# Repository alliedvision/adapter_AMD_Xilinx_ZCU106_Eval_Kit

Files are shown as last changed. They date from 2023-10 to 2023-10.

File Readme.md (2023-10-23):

# Allied Vision Adapter Board CSI-2 for AMD Xilinx ZCU106 Eval Kit

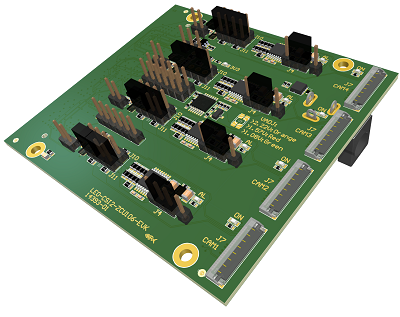
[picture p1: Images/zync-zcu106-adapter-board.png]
zync zcu106 adapter board


This repository contains open hardware design files for an adapter board supporting the Allied Vision Alvium CSI-2 camera pinout to AMD Xilinx ZCU106 Eval Kit. The board allows the user to interface with up to four Alvium MIPI CSI-2 compatible cameras over a Flexible Flat Cable (FFC) connector.

You can also purchase the adapter from [Allied Vision](https://www.alliedvision.com/en/products/accessories/interface-connections/#!?cameraInterfacefilter=10) or from our [distributors](https://www.alliedvision.com/en/avt-locations/avt-distributors/).

## Getting Started

These instructions will get you a copy of the design files to make your own adapter boards for development and testing purposes. 
The board can be produced and assembled using the provided design files. Please take a look at the mechanical layers for more information regarding the PCB stackup recommended for fabrication. 

More information is available on our website:

* [User Guide (PDF)](https://cdn.alliedvision.com/fileadmin/content/documents/products/accessories/embedded/user-guide/Xilinx-ZCU106_Adapter_User-Guide.pdf)
* [Accessories webpage](https://www.alliedvision.com/en/products/accessories/interface-connections/#!?cameraInterfacefilter=10) 
* [Accessories download webpage](https://www.alliedvision.com/en/support/accessory-documentation/)
* [Alvium CSI-2 download webpage](https://www.alliedvision.com/en/support/technical-documentation/alvium-csi-2-documentation/) 

### Prerequisites

* A running installation of Altium.
* A PCB producer & PCBA manufacturer or some soldering skills.
* AMD Xilinx Zynq UltraScale+ MPSoC ZCU106 Evaluation Kit
* Supported MIPI CSI-2 FPC cables, Allied Vision product codes
 18947, 12316, 12317, 12318 
* [Allied Vision Alvium CSI-2 cameras](https://www.alliedvision.com/en/products/embedded-vision-cameras.html)

### Installing

Open the *CSI2-ZCU106-EVK_Rev01.PrjPcb* project file in your Altium environment.

## Built With

[Altium Designer 22](https://www.altium.com/altium-designer/de)
 
## License

This project is licensed under the MIT License - see the [LICENSE](LICENSE) file for details

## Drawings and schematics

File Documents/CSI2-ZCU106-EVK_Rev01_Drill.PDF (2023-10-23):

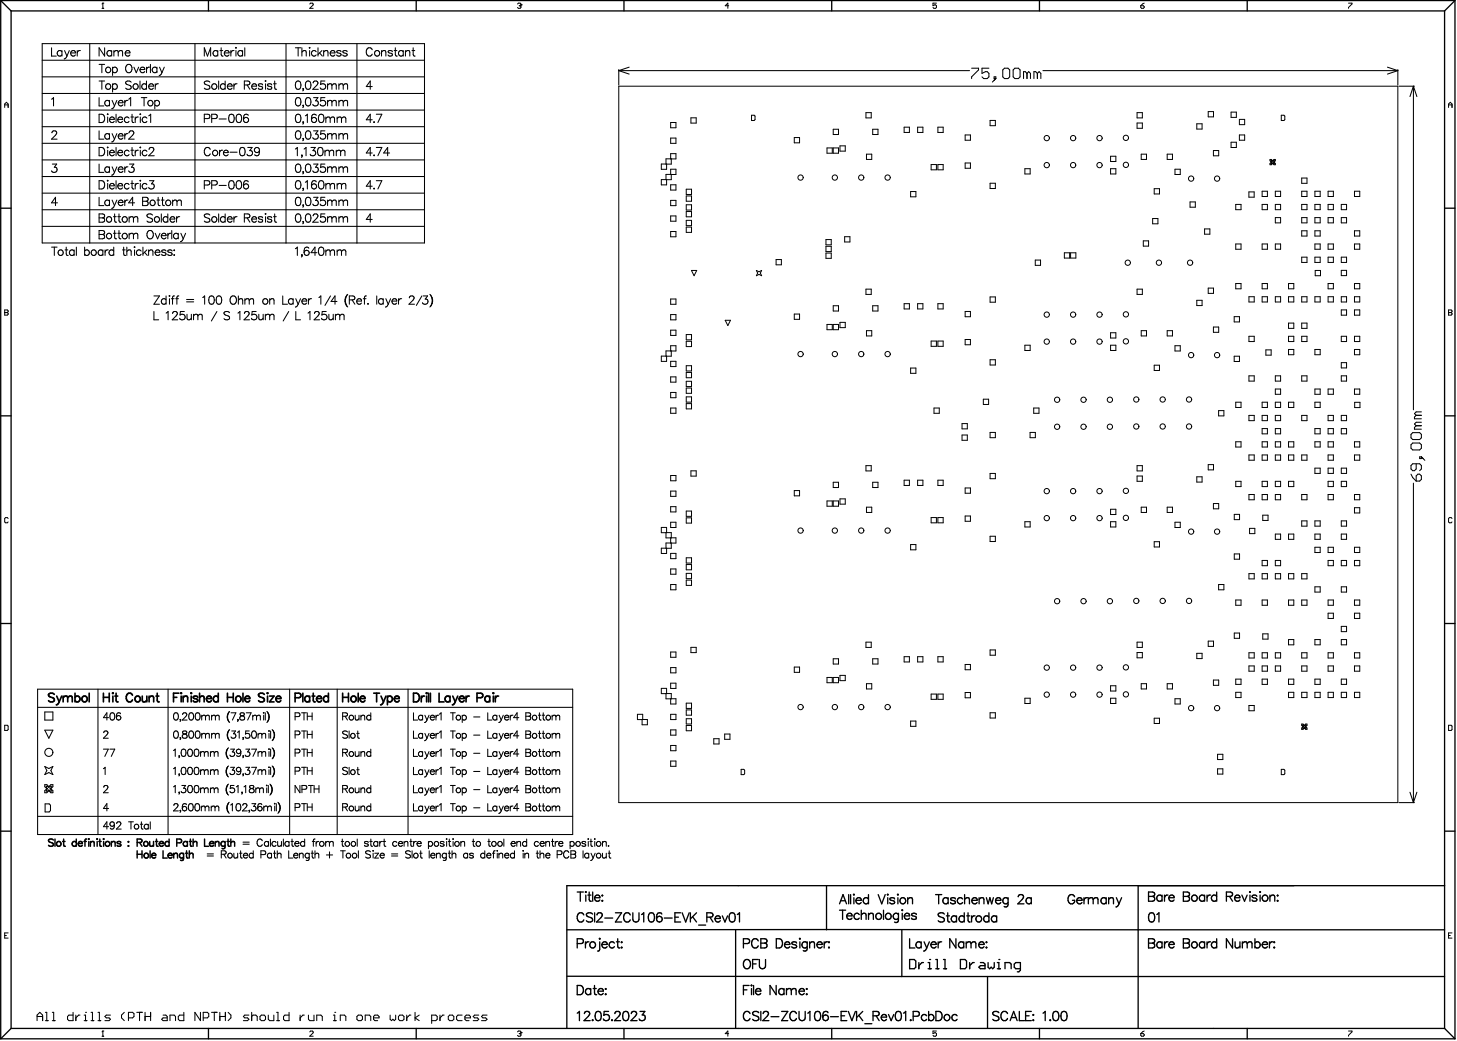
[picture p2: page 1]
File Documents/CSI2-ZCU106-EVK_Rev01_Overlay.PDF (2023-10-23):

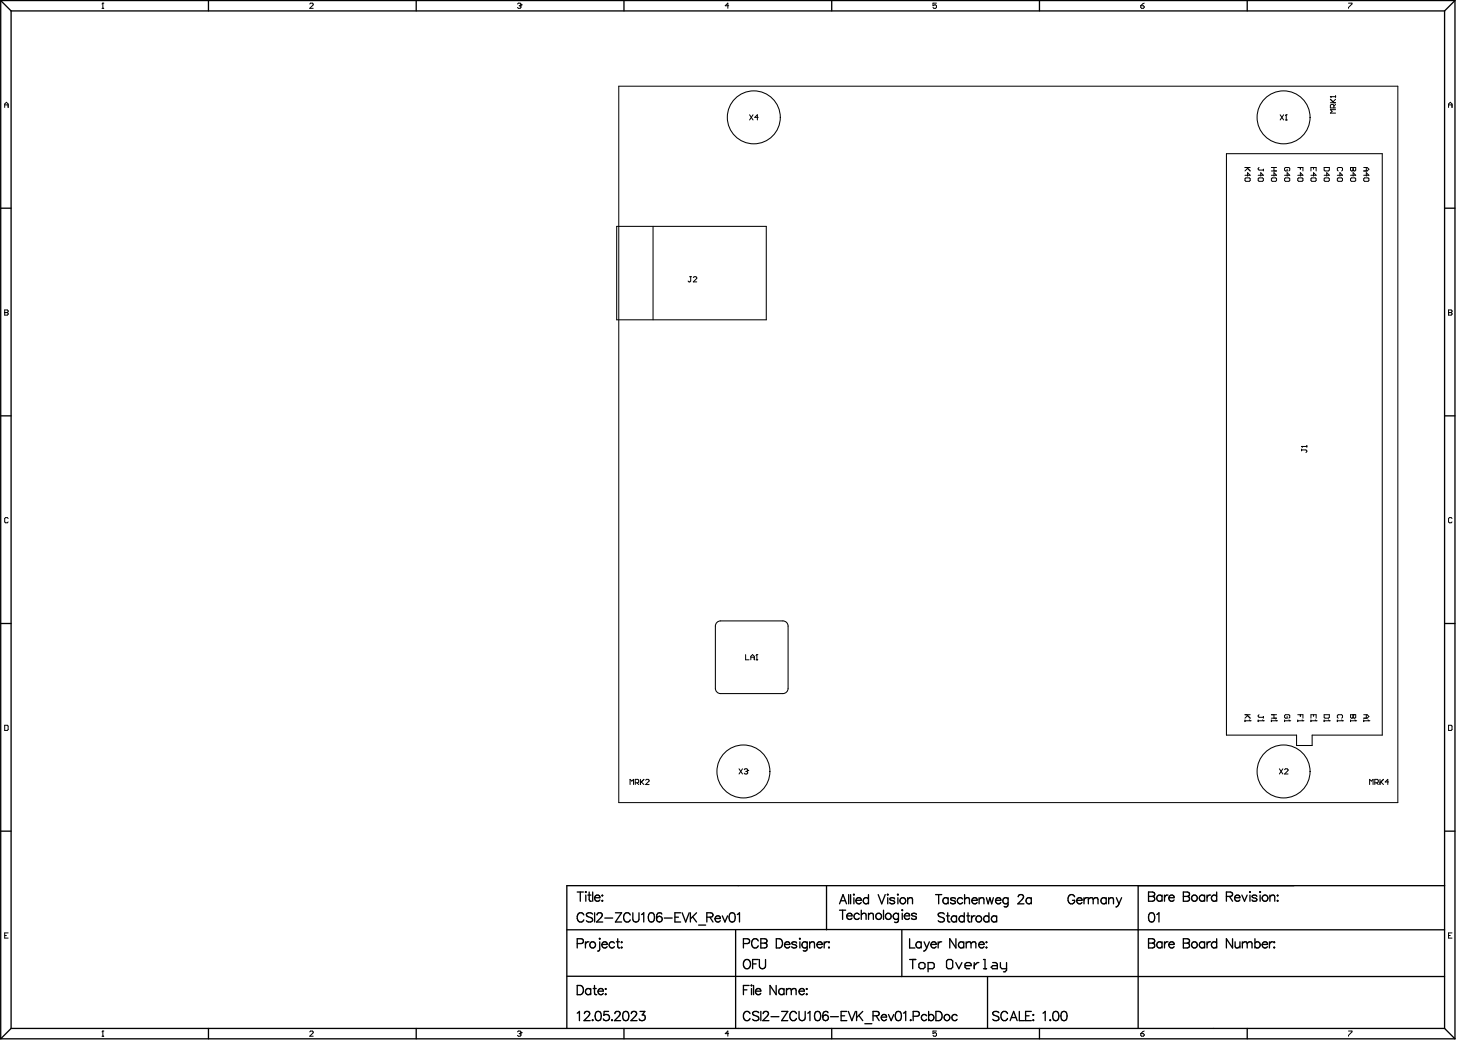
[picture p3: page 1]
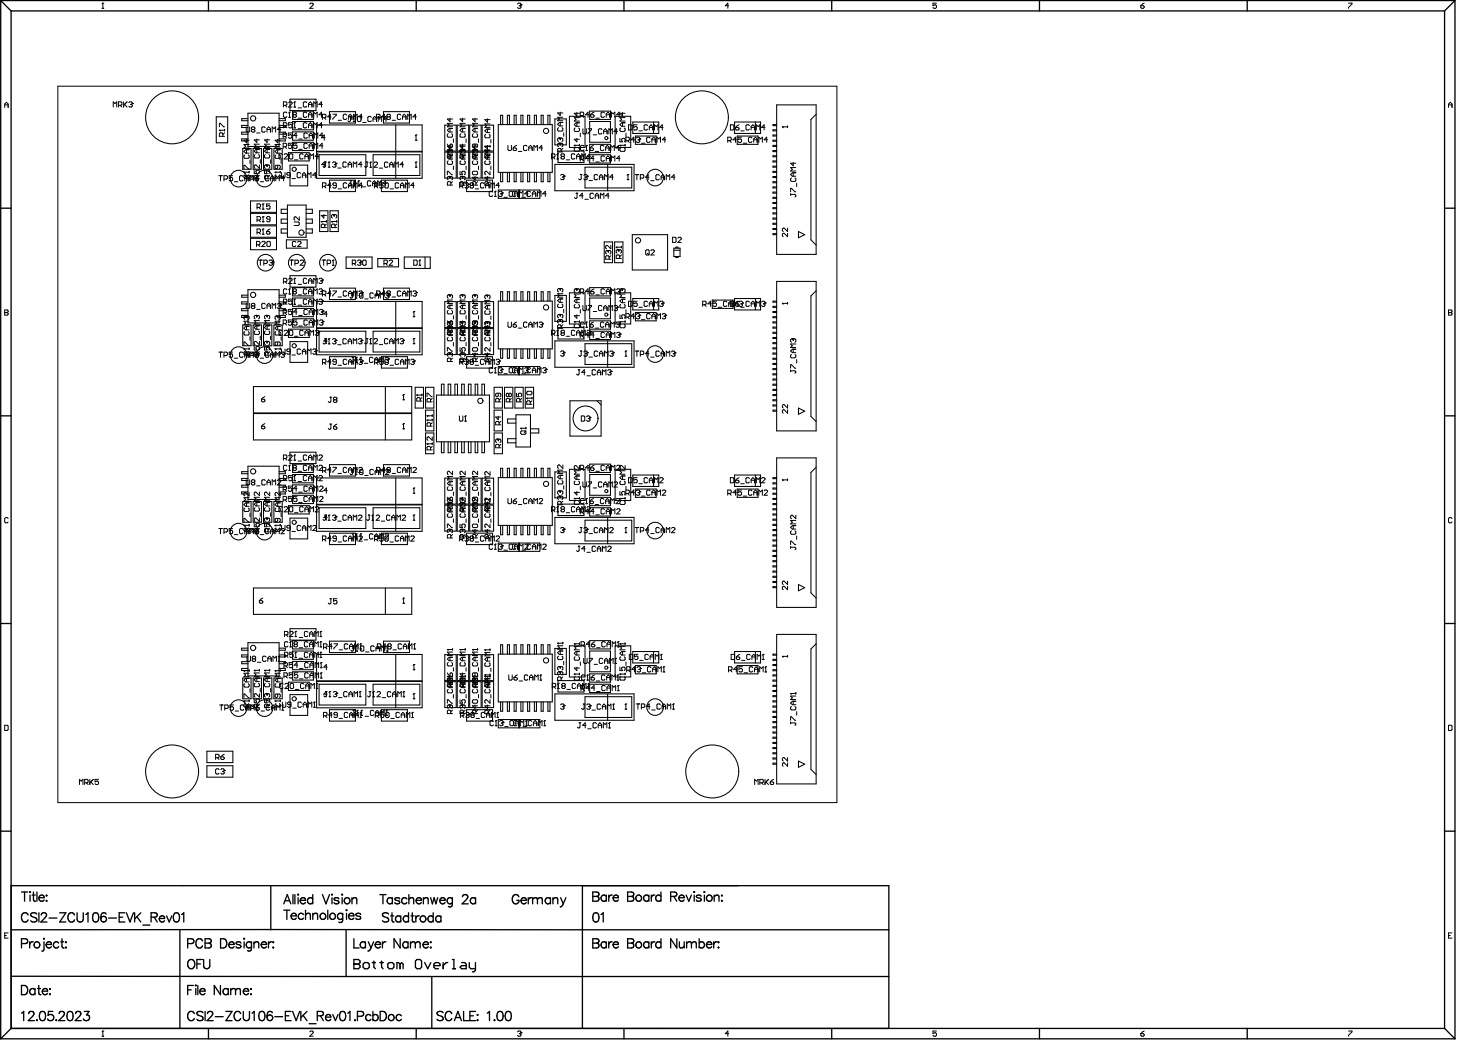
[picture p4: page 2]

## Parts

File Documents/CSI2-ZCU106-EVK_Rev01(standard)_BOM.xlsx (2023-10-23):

 | Bill of Materials | CSI2-ZCU106-EVK_Rev01
 | Project :
 | PCBA : |  | Revision : | 01
 | PCB : |  | Revision : | 01
 | Variant : | standard
 | Schematic : | CSI2-ZCU106-EVK_Rev01 | Schematic.pdf
 | Placement : | CSI2-ZCU106-EVK_Rev01 | Overlay.pdf
 | Report Date : | 12.05.2023 | 14:08
 | Alternative Parts :
Quantity | Designator | Comment | Footprint | Description | Manufacturer | Manufacturer Part Number | KHK Part Number
25 | C1_CAM1, C1_CAM2, C1_CAM3, C1_CAM4, C2, C13_CAM1, C13_CAM2, C13_CAM3, C13_CAM4, C16_CAM1, C16_CAM2, C16_CAM3, C16_CAM4, C17_CAM1, C17_CAM2, C17_CAM3, C17_CAM4, C19_CAM1, C19_CAM2, C19_CAM3, C19_CAM4, C20_CAM1, C20_CAM2, C20_CAM3, C20_CAM4 | 100n | C-0402_0.55 | Capacitor Ceramic SMD/0402/16V/X7R/10% | several | several | K8340114
1 | C3 | NL | C-0603_1.0 | Capacitor Ceramic SMD/0603/50V/X7R/10% | several | several
8 | C14_CAM1, C14_CAM2, C14_CAM3, C14_CAM4, C15_CAM1, C15_CAM2, C15_CAM3, C15_CAM4 | 10u | C-0805_1.4 | Capacitor Ceramic SMD/0805/16V/X5R/10% | several | several | K8340151
4 | C18_CAM1, C18_CAM2, C18_CAM3, C18_CAM4 | 100p | C-0402_0.55 | Capacitor Ceramic SMD/0402/50V/X7R/10% | several | several | K8340145
5 | D1, D6_CAM1, D6_CAM2, D6_CAM3, D6_CAM4 | GREEN | D-0603-LED | Chip LED green 430mcd | Würth | 150060GS75000 | 8172
1 | D2 | ESD9B5.0ST5G | D-SOD923 | DIODE TVS; 400W; 5.8-7.8V; BIDIRECT | ON Semiconductor | ESD9B5.0ST5G | 7250
1 | D3 | RT/GN | LED-PLCC4 | LED red/green | OSRAM | LSG T67K-JL-1+HK-1 | 11105
4 | D5_CAM1, D5_CAM2, D5_CAM3, D5_CAM4 | RED | D-0603-LED | Chip LED red 250mcd | Würth | 150060RS75000 | 8145
1 | J1 | FMC HPC Male | J-ASP-134488-01 | CON FMC HPC MALE 10MM | Samtec | ASP-134488-01 | 9159
1 | J2 | PowerJack | CON_RAPC722 | Switchcraft PowerJack RAPC722 / 2.1mm (Inner) / 6mm (Outer) | Switchcraft | RAPC722X | K7600556
12 | J3_CAM1, J3_CAM2, J3_CAM3, J3_CAM4, J12_CAM1, J12_CAM2, J12_CAM3, J12_CAM4, J13_CAM1, J13_CAM2, J13_CAM3, J13_CAM4 | Jumper | J-JUMPER-2.54 | CON/JUMPER/STC02SYAN; 2-pin; 2.54mm; 3A; FEMALE; VERTICAL; BLACK | several | several | 13444
4 | J4_CAM1, J4_CAM2, J4_CAM3, J4_CAM4 | CON1x3 | CON 1x3 RM2.54 | Header Vertical, 1x3 Pos, Pitch 2.54mm, Contact Length Mating 6.00mm, Contact Length Post 3.00mm, Insulation Height 2.54mm, Gold Plating | several | several | 15338
3 | J5, J6, J8 | CON1x6 | CON 1x6 RM2.54 | Header Vertical, 1x6 Pos, Pitch 2.54mm, Contact Length Mating 6.00mm, Contact Length Post 3.00mm, Insulation Height 2.54mm, Gold Plating | several | several | 15686
4 | J7_CAM1, J7_CAM2, J7_CAM3, J7_CAM4 | CON FFC22_Inverted | J-FH55-22S-0.5SH - Inverted Pins | FFC Connector 0.5mm shielded | Hirose | FH55-22S-0.5SH | 10357
4 | J11_CAM1, J11_CAM2, J11_CAM3, J11_CAM4 | CON1x4 | CON 1x4 RM2.54 | Header Vertical, 1x4 Pos, Pitch 2.54mm, Contact Length Mating 6.00mm, Contact Length Post 3.00mm, Insulation Height 2.54mm, Gold Plating | several | several | 15343
1 | LA1 | LABEL 7x7mm | PCB LABEL 7x7 | LABEL 7x7mm | several | several
6 | MRK1, MRK2, MRK3, MRK4, MRK5, MRK6 | Marker Single Layer | PCB_Marker_Pad_top | Position Marker for PCBs
1 | PCB1 | CSI2-ZCU106-EVK |  | PCB ML04SF | several | 14393-01 | 14393-01
1 | Q1 | BC847C | IC-SOT23-3 | TRANSISTOR NPN 100mA 45V | several | BC847C | 16587
1 | Q2 | Si7629DN | IC-POWERPAK_1212-8_3.4x3.4x1.1 | P-Channel MOSFET 20V | Vishay | Si7629DN | 3619
8 | R1, R12, R13, R14, R45_CAM1, R45_CAM2, R45_CAM3, R45_CAM4 | 3k3 | R-0402_0.4 | Standard Resistor SMD/0402/1%/63mW/TK100 | several | several | K8250347
6 | R2, R11, R43_CAM1, R43_CAM2, R43_CAM3, R43_CAM4 | 1k5 | R-0402_0.4 | Standard Resistor SMD/0402/1%/63mW/TK100 | several | several | K8250358
6 | R3, R4, R5, R9, R31, R32 | 10k | R-0402_0.4 | Standard Resistor SMD/0402/1%/63mW/TK100 | several | several | K8250264
27 | R6, R17, R21_CAM1, R21_CAM2, R21_CAM3, R21_CAM4, R30, R35_CAM1, R35_CAM2, R35_CAM3, R35_CAM4, R38_CAM1, R38_CAM2, R38_CAM3, R38_CAM4, R41_CAM1, R41_CAM2, R41_CAM3, R41_CAM4, R47_CAM1, R47_CAM2, R47_CAM3, R47_CAM4, R48_CAM1, R48_CAM2, R48_CAM3, R48_CAM4 | 0R0 | R-0603_0.6 | Standard Resistor SMD/0603/1%/100mW/TK200 | several | several | K8250041
17 | R7, R52_CAM1, R52_CAM2, R52_CAM3, R52_CAM4, R53_CAM1, R53_CAM2, R53_CAM3, R53_CAM4, R54_CAM1, R54_CAM2, R54_CAM3, R54_CAM4, R55_CAM1, R55_CAM2, R55_CAM3, R55_CAM4 | 2k0 | R-0402_0.4 | Standard Resistor SMD/0402/1%/63mW/TK100 | several | several | K8250311
2 | R8, R10 | 240R | R-0402_0.4 | Standard Resistor SMD/0402/1%/63mW/TK100 | several | several | 7256
44 | R15, R16, R18_CAM1, R18_CAM2, R18_CAM3, R18_CAM4, R19, R20, R33_CAM1, R33_CAM2, R33_CAM3, R33_CAM4, R34_CAM1, R34_CAM2, R34_CAM3, R34_CAM4, R36_CAM1, R36_CAM2, R36_CAM3, R36_CAM4, R37_CAM1, R37_CAM2, R37_CAM3, R37_CAM4, R39_CAM1, R39_CAM2, R39_CAM3, R39_CAM4, R40_CAM1, R40_CAM2, R40_CAM3, R40_CAM4, R42_CAM1, R42_CAM2, R42_CAM3, R42_CAM4, R49_CAM1, R49_CAM2, R49_CAM3, R49_CAM4, R50_CAM1, R50_CAM2, R50_CAM3, R50_CAM4 | NL | R-0603_0.6 | Standard Resistor SMD/0603/1%/100mW/TK200
4 | R44_CAM1, R44_CAM2, R44_CAM3, R44_CAM4 | 270K | R-0402_0.4 | Standard Resistor SMD/0402/1%/63mW/TK100 | several | several | 3875
4 | R46_CAM1, R46_CAM2, R46_CAM3, R46_CAM4 | 51k | R-0402_0.4 | Standard Resistor SMD/0402/1%/63mW/TK100 | several | several | K8250273
4 | R51_CAM1, R51_CAM2, R51_CAM3, R51_CAM4 | 200k | R-0402_0.4 | Standard Resistor SMD/0402/1%/63mW/TK100 | several | several | K8250280
1 | U1 | LM2901DTBR2G | IC-SO14_5.1x6.6x1.2 | QUAD COMPERATOR | ON Semi | LM2901DTBR2G
1 | U2 | 24LC025T-I/OT | IC-SOT23-6 | 2K I2C Serial EEPROM 2V5-5V5 | Microchip | 24LC025T-I/OT | 9217
4 | U6_CAM1, U6_CAM2, U6_CAM3, U6_CAM4 | INA260AIPWR | IC-TSSOP16 6.4x5.1x1.2 | IC/PWR/CURR SHUNT MONITOR/2.7-5.5V;4.5mR/TSSOP16/5.0x4.4x1.2mm | TI | INA260AIPWR
4 | U7_CAM1, U7_CAM2, U7_CAM3, U7_CAM4 | TPS25200DRVT | IC-DFN06_2.0x2.0x0.8 | IC/PWR/LOADSW;2V5-6V5;2A5;0R099/6-WDFN/2x2x0.8mm | Texas Instruments | TPS25200DRVT | 14277
4 | U8_CAM1, U8_CAM2, U8_CAM3, U8_CAM4 | PCA9306DCTR | IC-TSSOP8_3.15x4.25x1.3 | IC/LOGIC/LEVELSHIFTER;I2C;AUTO-DIR;1V2-5V/SSOP-8/4.25x3.15x1.3mm | TI | PCA9306DCTR | 9555
4 | U9_CAM1, U9_CAM2, U9_CAM3, U9_CAM4 | NTB0104GU12,115 | IC-XQFN12_1.7x2x0.5 | IC/LOGIC/Levelshifter;Auto-Dir;Bidirectional;Push-Pull;-40-+125°C/ | NXP | NTB0104GU12,115 | 14383
